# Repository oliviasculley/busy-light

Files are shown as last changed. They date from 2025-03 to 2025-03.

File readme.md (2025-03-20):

# Busy Light

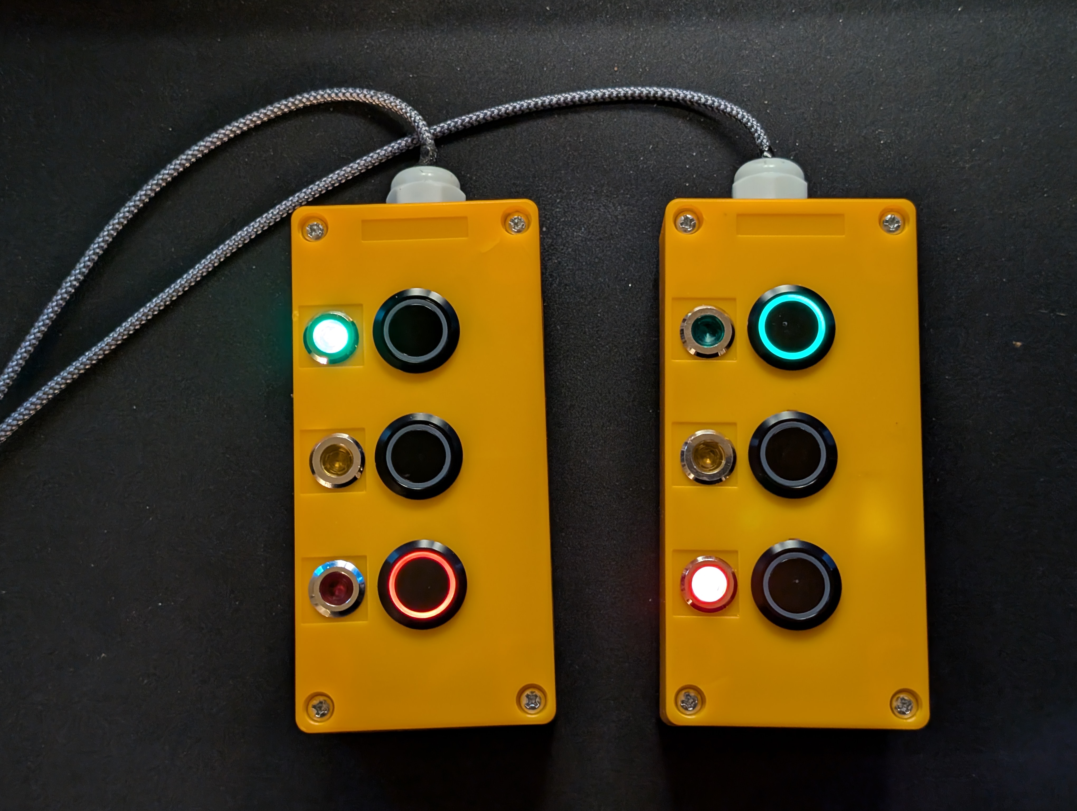
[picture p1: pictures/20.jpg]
Image of the busy light control boxes


This repo contains the schematics, PCB files and media for a synced busy-light
control box that can be used to communicate up to 4 states, indicated with LEDs. The wireless communication is fault-tolerant and utilizes encrypted ESP-NOW for communication, which means that it doesn't have any other dependencies besides power and your communications are secure!

## Schematic and PCB

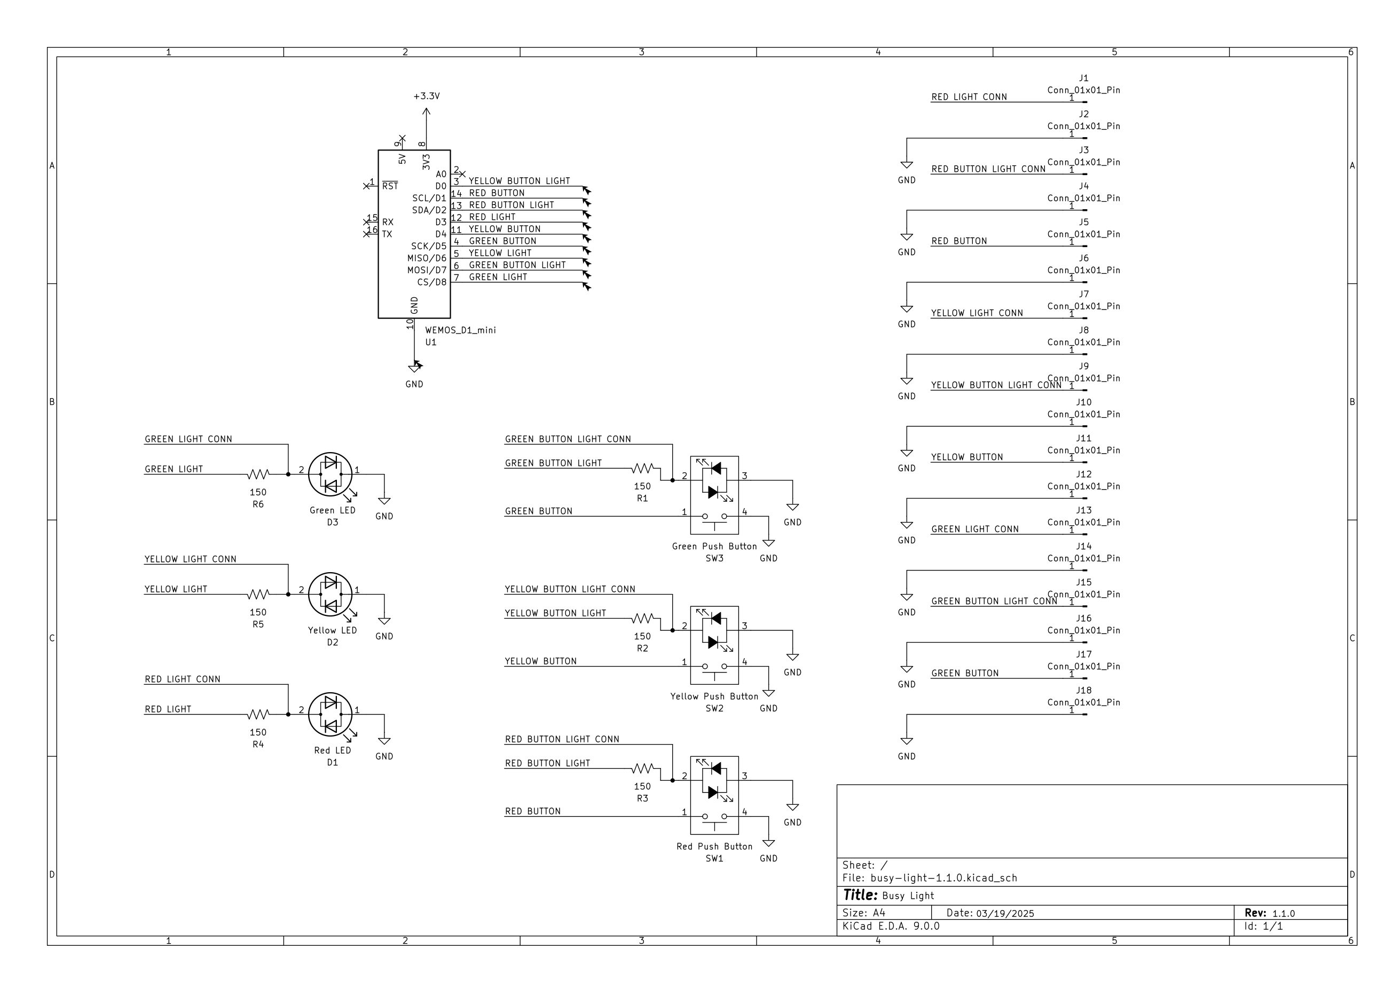
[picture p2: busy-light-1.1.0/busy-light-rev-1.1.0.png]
Busy light schematic

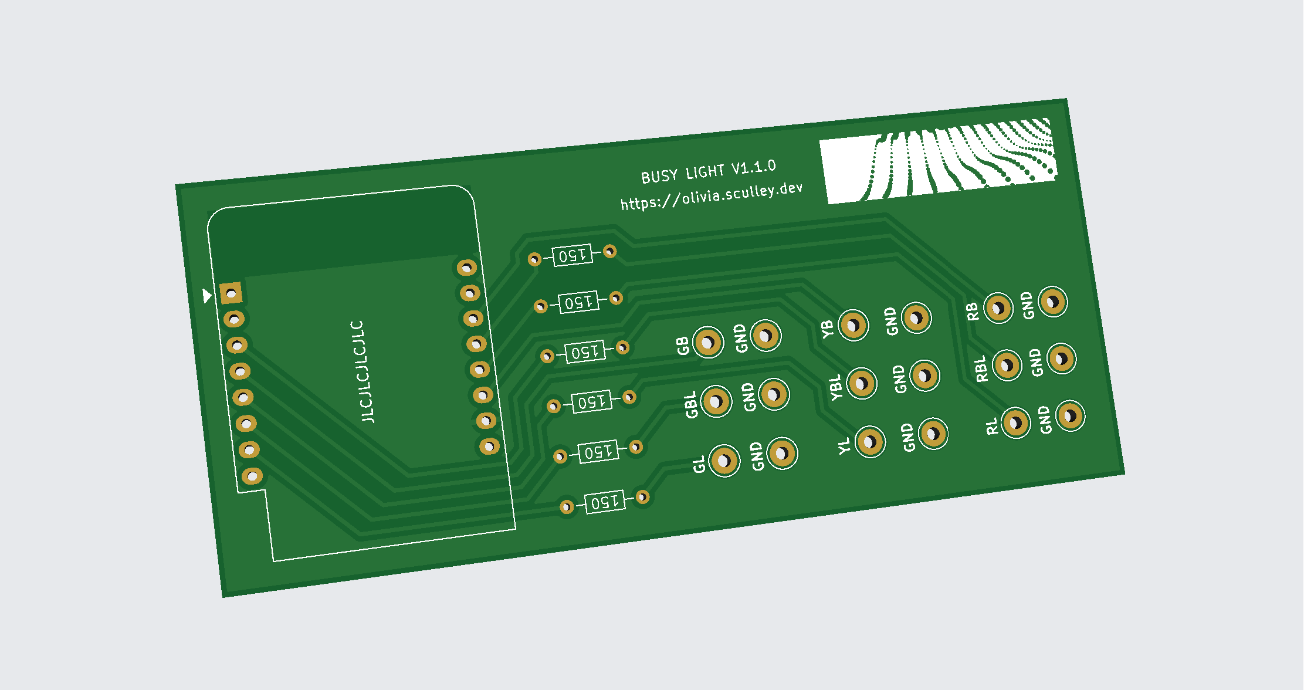
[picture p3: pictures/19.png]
A 3D view of the v1.1.0 revision of the PCB board


## Components

- [22mm 3x Control box](https://www.aliexpress.us/item/3256805247196863.html)
- [Red, Yellow and Green buttons](https://www.aliexpress.us/item/3256803827064988.html)
- [Button connector leads](https://www.aliexpress.us/item/3256803827064988.html)
- [LED Status Lights](https://www.aliexpress.us/item/2251832784127555.html)
- [Through-hole resistors](https://www.aliexpress.us/item/3256807885719870.html)
- [Wemos D1 Mini ESP 8266](https://www.amazon.com/dp/B081PX9YFV)
- [USB power brick](https://www.amazon.com/dp/B08H5421TJ)
- [Micro-USB cable](https://www.amazon.com/dp/B0D7RZJSPS)

Estimated part costs (without shipping):
- Two 22mm 3x Control boxes: $6.62
- Red, Yellow and Green buttons and connector leads: $20.76
- LED Status Lights: $5.34
- Wemos D1 Mini ESP 8266s: $12.98
- Through-hole resistors: $2.68
- USB power bricks: $11.99
- Micro-USB cables: $5.49

Estimated Total: around $66 for 2 boxes, or around $33 each

## Tools required

- Screwdriver
- Small eyeglasses screwdriver
- Soldering iron
- Solder
- Solid core wires
- Wire stripper
- Arduino IDE
- Kicad

## Assembly notes

- Use blue and white leads for button switches
- Use 150 ohm resistors for all LEDs
- For the Arduino IDE, you will need the [ESP8266 library](https://github.com/esp8266/Arduino) installed
- Epoxy putty around the cable is optional but recommended!
- To order the boards from JLCPCB yourself, visit the releases to download the compiled gerber files.
- The boards are set to 9600 baud serial
- Use serial to determine the board's mac addresses
- Then, fill in `BROADCAST_ADDRESS[]` with both boards' mac addresses
- Toggle the `#if true` between true and false to flash corresponding boxes
- (Optional) Set a new 16 char encryption key for better security

## Repository structure
- `busy-light-1.0.0/` contains the original version of the board that I created on a protoboard
- `busy-light-1.1.0/` contains the fabbed version of the board. I have yet to receive these boards and test them so no guarantees that it actually works! (although I have high hopes)

## Potential future changes
- Add mounting for PCB (Mounting holes?)
- Add mounting for Micro-USB cable
- Use FreeRTOS if I feel like writing a lot of boilerplate

## Project Log

1. The first prototype boards
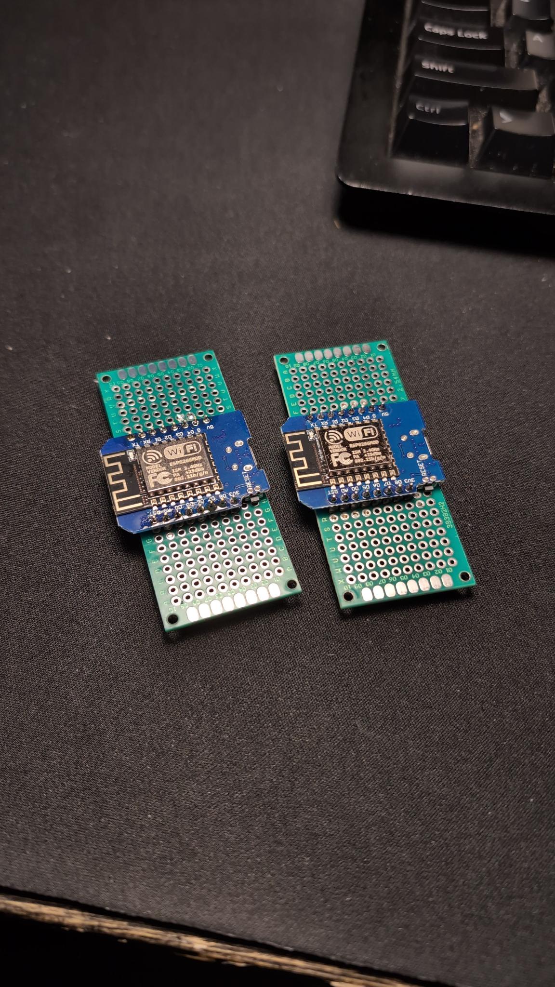
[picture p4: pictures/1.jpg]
The first prototype boards
   
1. Soldering the resistors
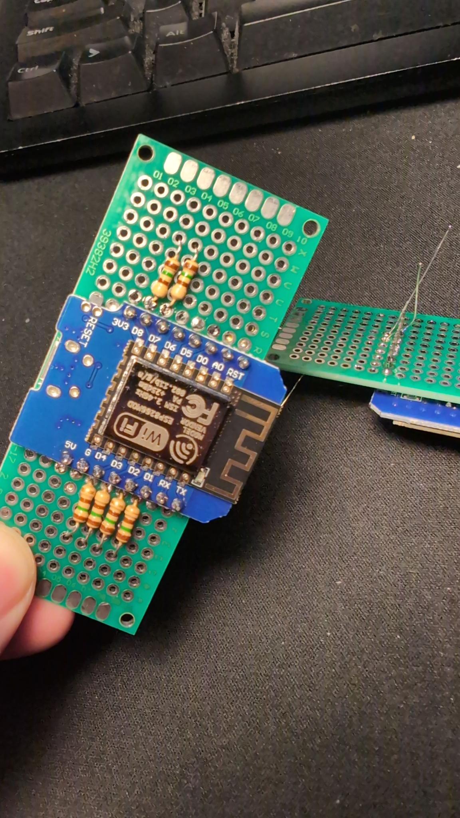
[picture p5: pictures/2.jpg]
Soldering the resistors
   
1. Wrapping wires around pins
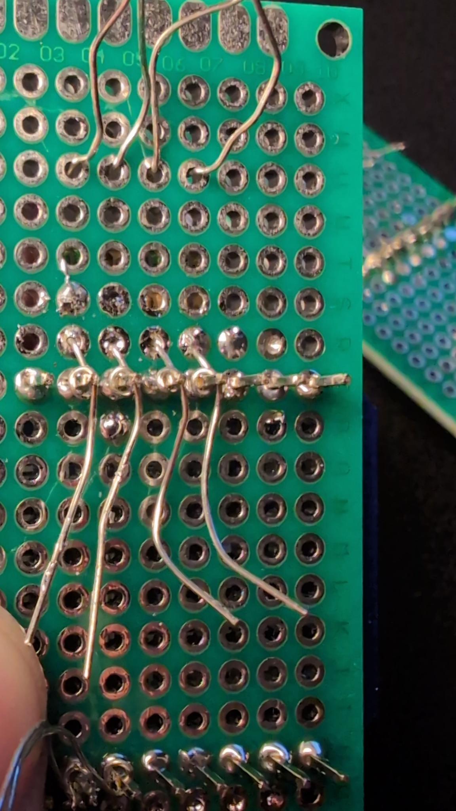
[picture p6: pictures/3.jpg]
Wrapping wires around pins
   
1. Trimmed wires
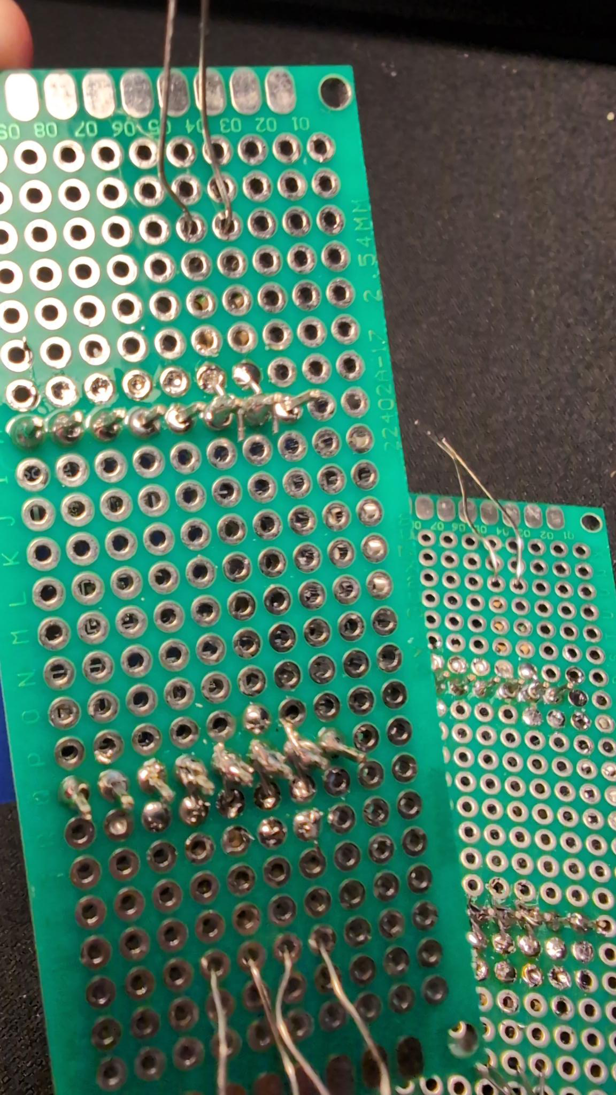
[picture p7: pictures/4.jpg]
Trimmed wires
   
1. Wired up prototype boards. Do you see the mistake?
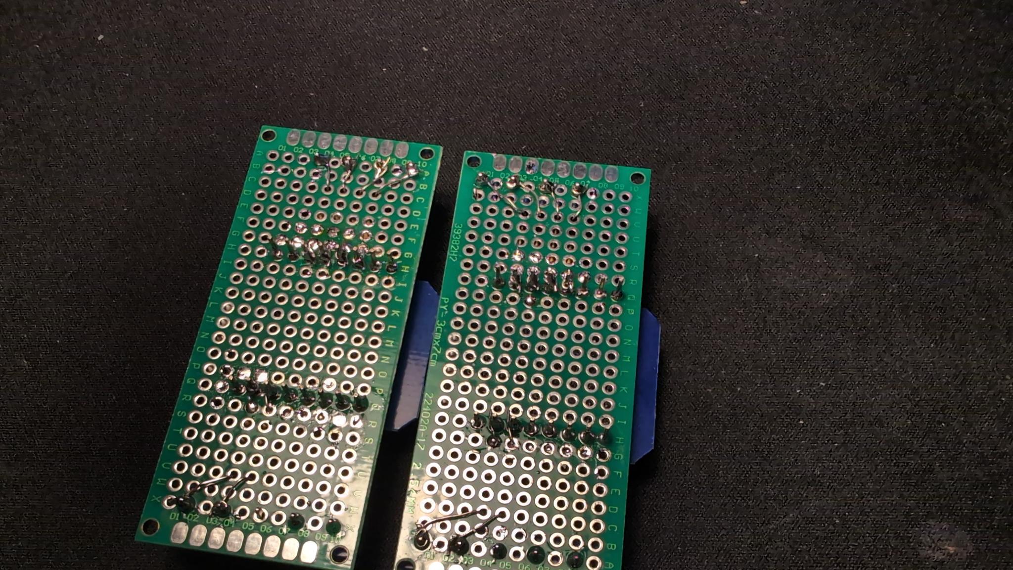
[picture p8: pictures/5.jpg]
Wired up prototype boards. Do you see the mistake?
   
1. Adding screw terminals
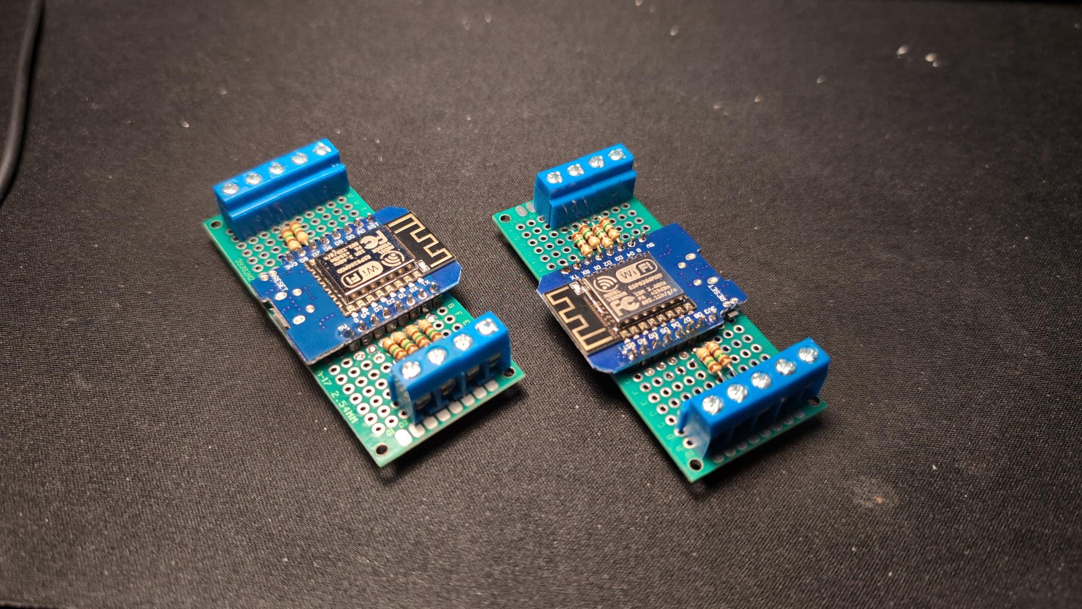
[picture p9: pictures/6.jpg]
Adding screw terminals
   
1. Fixing my mistake (Please excuse the soldering, most of this project was done after midnight 😅😅😅)
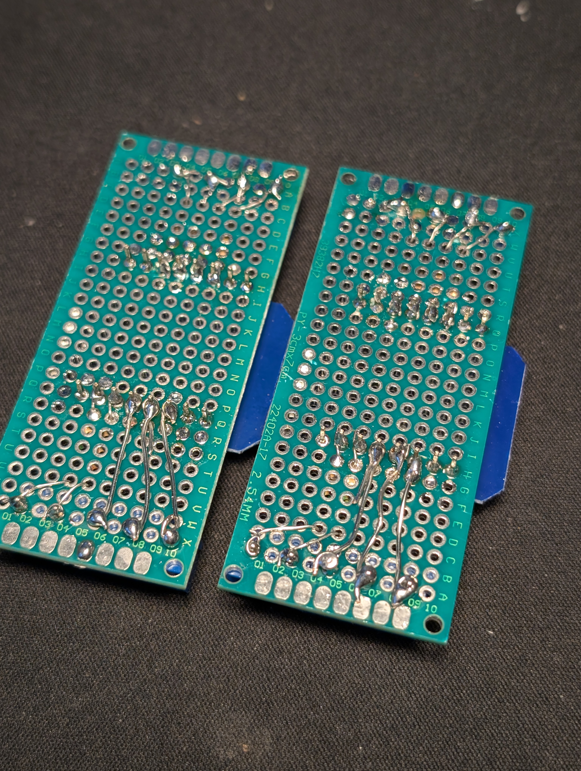
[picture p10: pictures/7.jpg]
Fixing my mistake
   
1. Wiring up buttons and lights
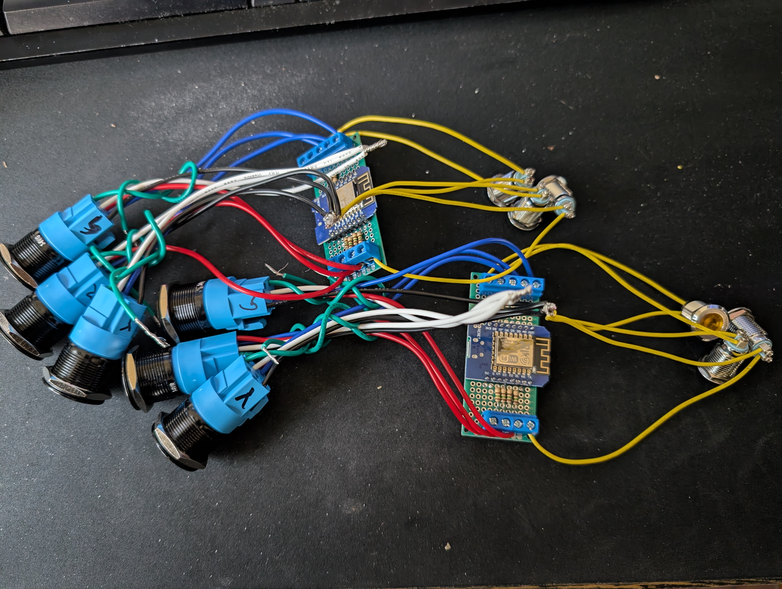
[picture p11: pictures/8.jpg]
Wiring up buttons and lights
   
1. Installing switches into control boxes
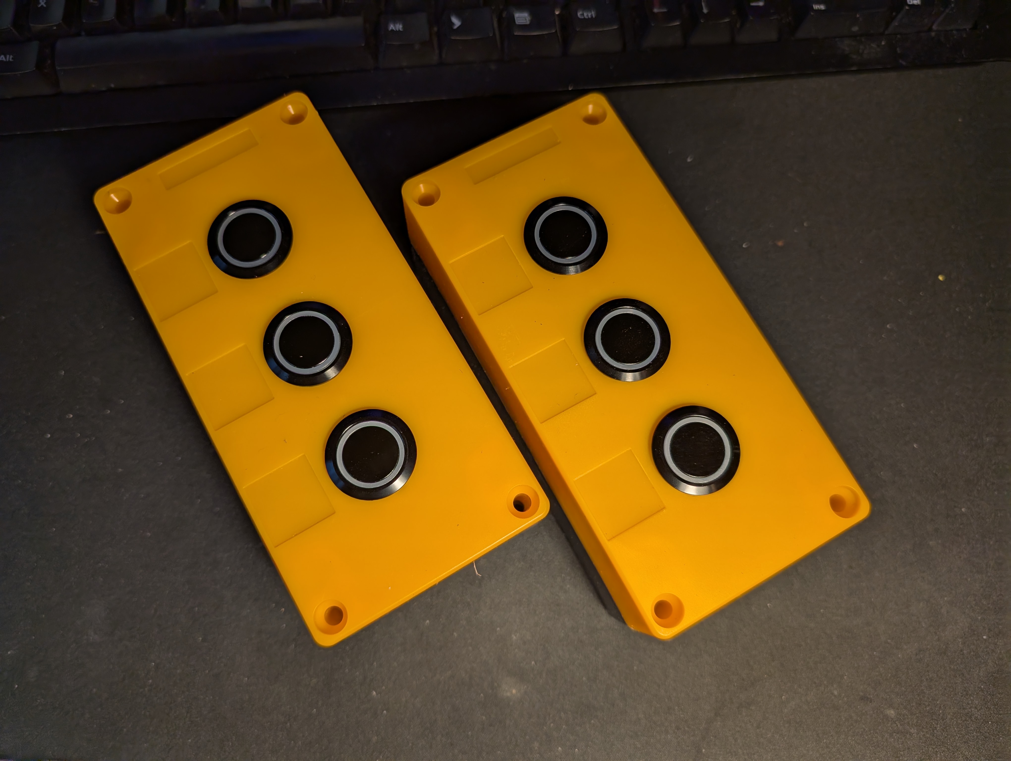
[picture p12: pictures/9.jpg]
Installing switches into control boxes
   
1. Adding a pull-up resistor to pin D0. Turns out that the ESP8266 doesn't have a usable internal pull-up on D0. Something to keep in mind!
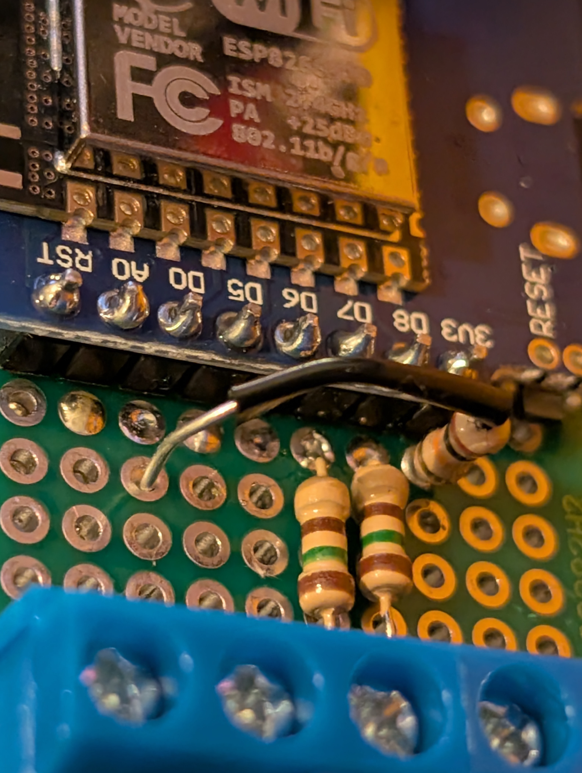
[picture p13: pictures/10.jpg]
Adding a pull-up resistor
   
1. The boxes mid-assembly!
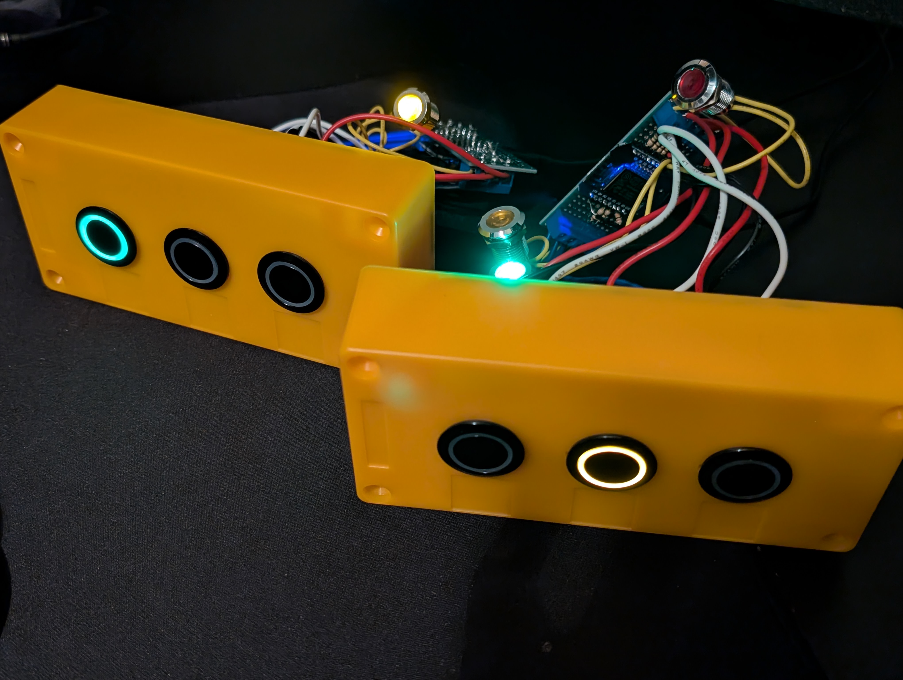
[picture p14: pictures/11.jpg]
The boxes mid-assembly!
   
1. Filling the end-caps with epoxy putty
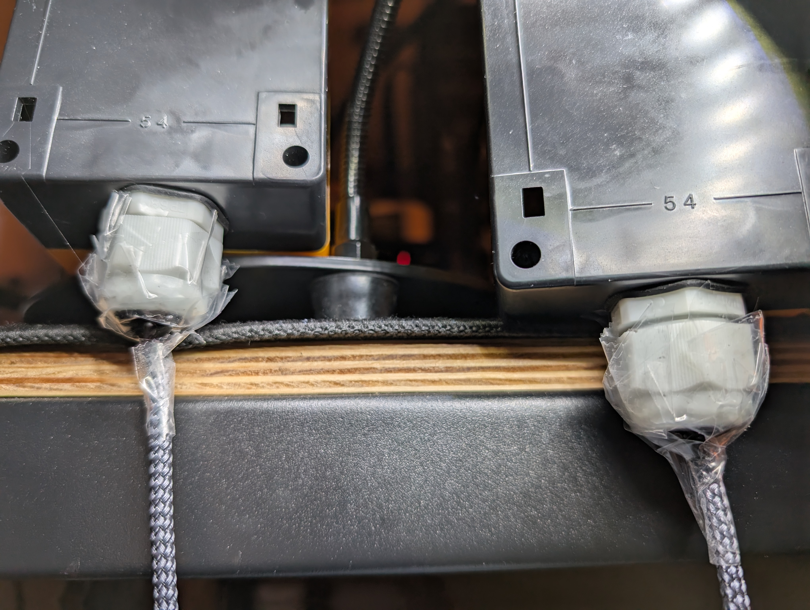
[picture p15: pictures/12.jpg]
Filling the end-caps with epoxy putty
   
1. An early version of the PCB board
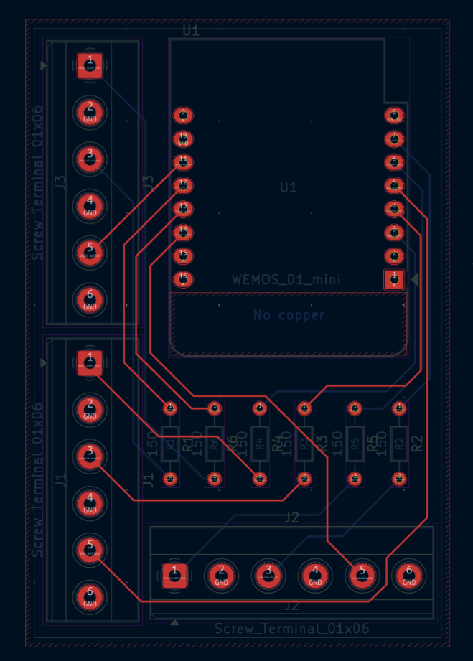
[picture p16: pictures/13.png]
An early version of the PCB board front
   
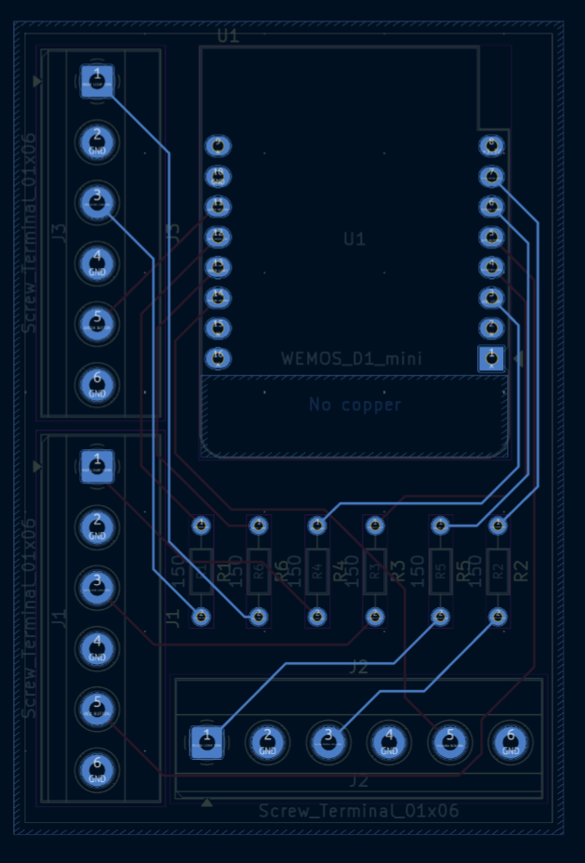
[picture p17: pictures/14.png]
An early version of the PCB board back
   
1. A 3D view of an early version of the PCB board
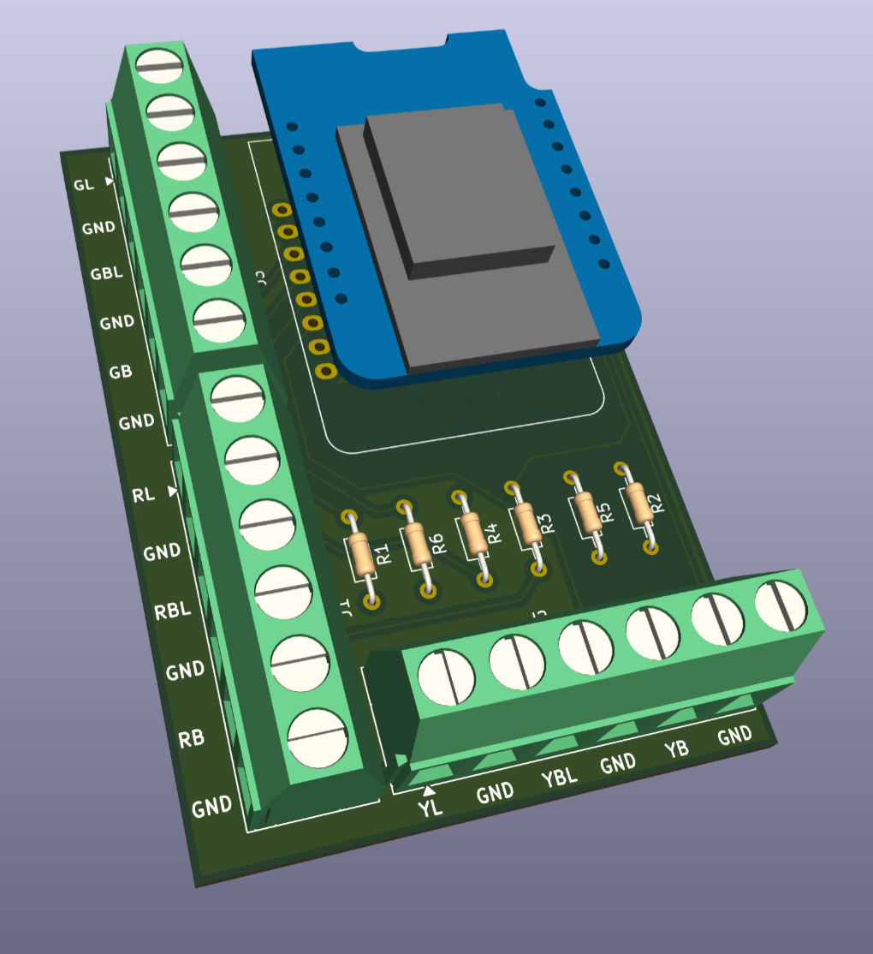
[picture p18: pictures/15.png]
A 3D view of an early version of the PCB boardboards
   
1. A 3D view of an early version of just the PCB board
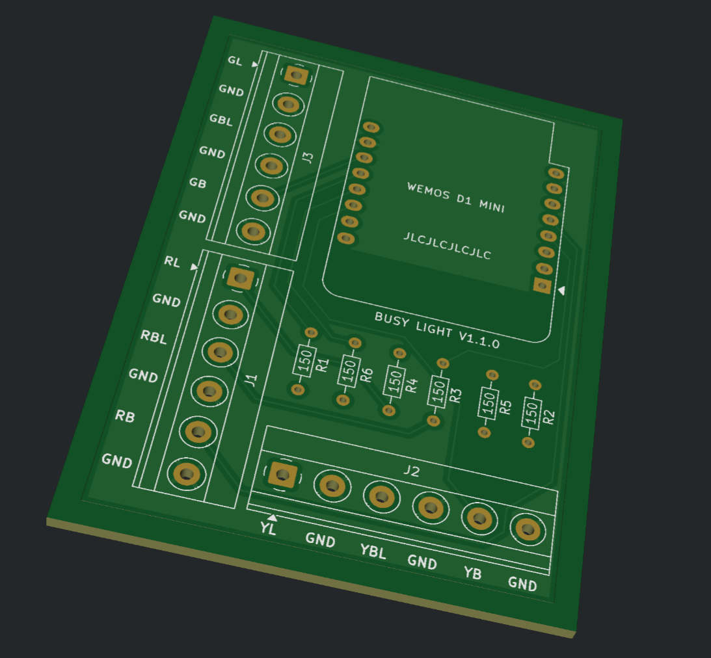
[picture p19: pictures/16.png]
A 3D view of an early version of just the PCB board
   
1. A 3D view of another revision of the PCB board
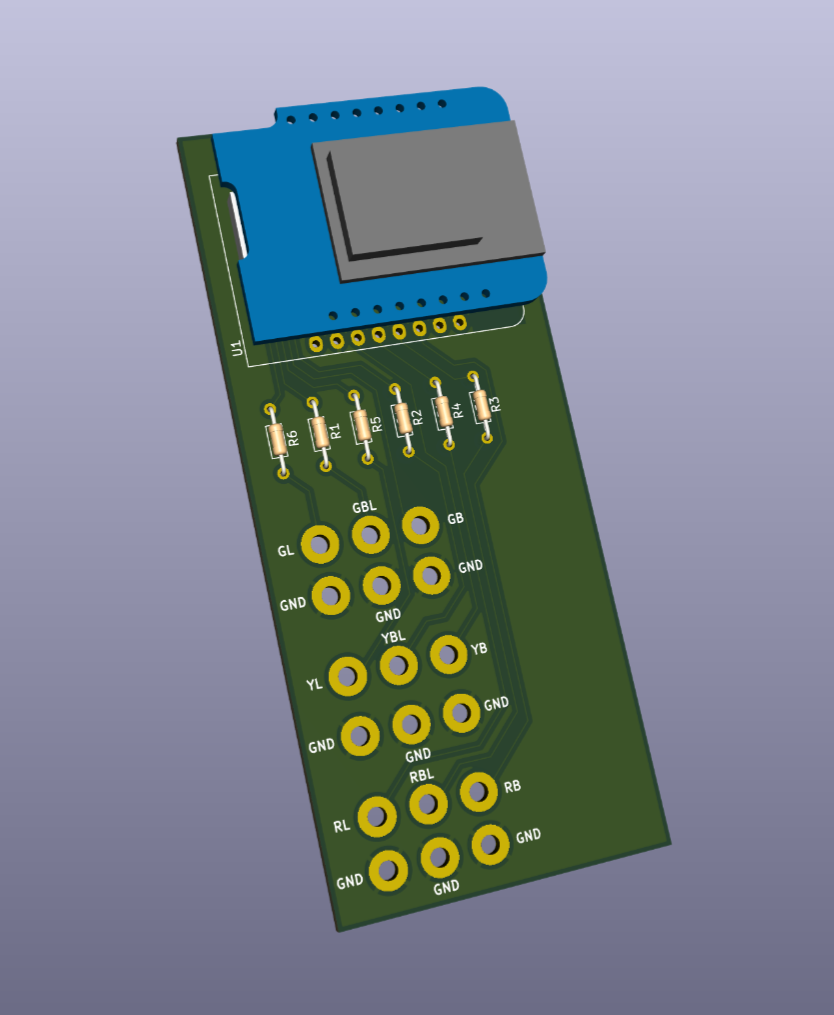
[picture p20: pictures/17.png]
A 3D view of another revision of the PCB board
   
1. A 3D view of the v1.1.0 revision of just the PCB board
   A 3D view of the v1.1.0 revision of just the PCB board
1. The final working prototypes! (Not using the fabbed boards yet, stay tuned!)
   The final working prototypes! (Not using the fabbed boards yet, stay tuned!)

## Misc Notes

- Vf red led button: 1.87v @ 3.4v
- Vf yellow led button: 2.58v @ 3.5v
- Vf green led button: 2.54v @ 3.6v

---

- Vf red: 1.84v @ 3.7v
- Vf yellow: 1.92v @ 3.8v
- Vf green: 2.30v @ 4.0v

---

- (3 - 1.85) / 20 (milliamps) * 1000 = 57 ohm
- (3 - 2.6) / 20 (milliamps) * 1000 = 20 ohm
- (4 - 1.85) / 20 (milliamps) * 1000 = 108 ohm
- (4 - 2.6) / 20 (milliamps) * 1000 = 70 ohm
- 150 ohm resistors seem good enough

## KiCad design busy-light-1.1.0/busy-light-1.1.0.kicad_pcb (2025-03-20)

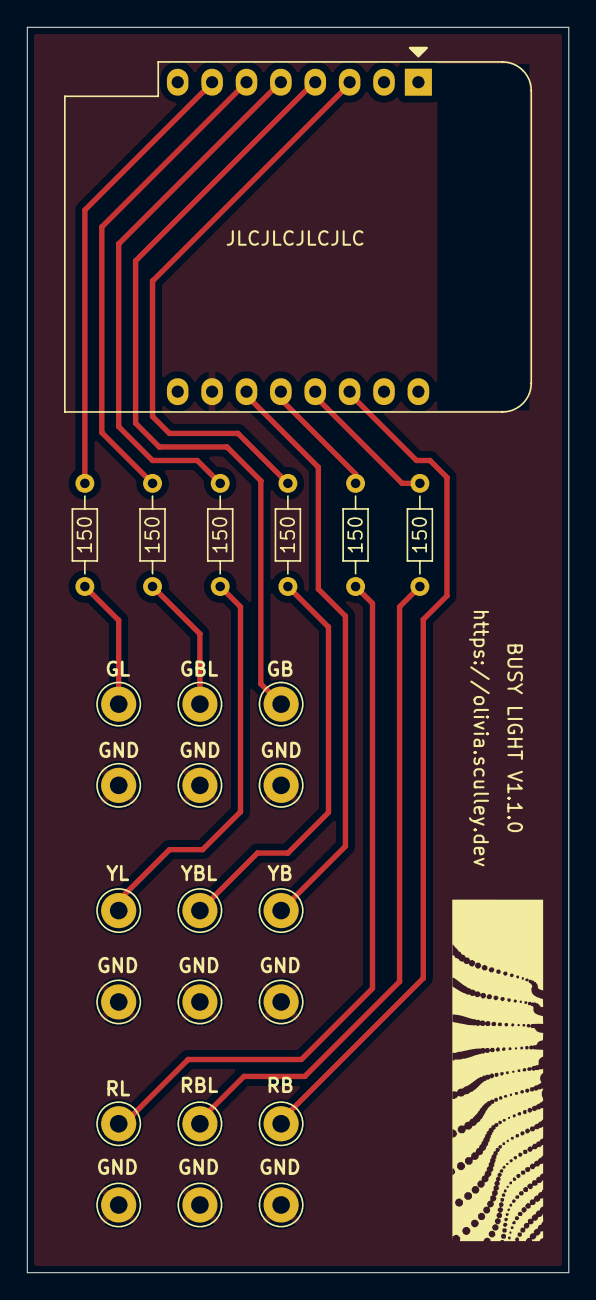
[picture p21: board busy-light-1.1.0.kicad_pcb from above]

Board: 4 copper layers, 40.0 x 92.0 mm, 25 parts (0 on the bottom side), 16 nets.

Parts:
J1, J2, J3, J4, J5, J6, J7, J8, J9, J10, J11, J12, J13, J14, J15, J16, J17, J18: Conn_01x01_Pin; Pin_D1.3mm_L11.0mm
R1, R2, R3, R4, R5, R6: 150; R_Axial_DIN0204_L3.6mm_D1.6mm_P7.62mm_Horizontal
U1: WEMOS_D1_mini; WEMOS_D1_mini_light

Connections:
/GREEN BUTTON: J17.1, U1.4 (SCK/D5)
/GREEN BUTTON LIGHT: R1.1, U1.6 (MOSI/D7)
/GREEN BUTTON LIGHT CONN: J15.1, R1.2
/GREEN LIGHT: R6.1, U1.7 (CS/D8)
/GREEN LIGHT CONN: J13.1, R6.2
/RED BUTTON: J5.1, U1.14 (SCL/D1)
/RED BUTTON LIGHT: R3.1, U1.13 (SDA/D2)
/RED BUTTON LIGHT CONN: J3.1, R3.2
/RED LIGHT: R4.1, U1.12 (D3)
/RED LIGHT CONN: J1.1, R4.2
/YELLOW BUTTON: J11.1, U1.11 (D4)
/YELLOW BUTTON LIGHT: R2.1, U1.3 (D0)
/YELLOW BUTTON LIGHT CONN: J9.1, R2.2
/YELLOW LIGHT: R5.1, U1.5 (MISO/D6)
/YELLOW LIGHT CONN: J7.1, R5.2
GND: J2.1, J4.1, J6.1, J8.1, J10.1, J12.1, J14.1, J16.1, J18.1, U1.10 (GND)

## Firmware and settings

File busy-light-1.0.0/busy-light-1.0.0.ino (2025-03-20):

#include <espnow.h>
#include <ESP8266WiFi.h>

#define RED_BUTTON_LIGHT D4
#define YELLOW_BUTTON_LIGHT D3
#define GREEN_BUTTON_LIGHT D2
#define RED_LIGHT D1
#define YELLOW_LIGHT D8
#define GREEN_LIGHT D7
#define RED_BUTTON D6
#define YELLOW_BUTTON D5
#define GREEN_BUTTON D0

const uint8_t BUTTON_LIGHTS[] = {
  RED_BUTTON_LIGHT,
  YELLOW_BUTTON_LIGHT,
  GREEN_BUTTON_LIGHT
};
const uint8_t STATUS_LIGHTS[] = { RED_LIGHT, YELLOW_LIGHT, GREEN_LIGHT };
const uint8_t BUTTONS[] = { RED_BUTTON, YELLOW_BUTTON, GREEN_BUTTON };

enum Status { NONE, NO_CALL, CAUTION, AUDIO_CALL, VIDEO_CALL };
Status selfStatus = NONE;
Status otherStatus = NONE;

// Toggle me to flash corresponding boxes
#if true
uint8_t BROADCAST_ADDRESS[] = {0x00, 0x00, 0x00, 0x00, 0x00, 0x00};
#else
uint8_t BROADCAST_ADDRESS[] = {0x00, 0x00, 0x00, 0x00, 0x00, 0x00};
#endif

unsigned char* ESPNOW_KEY = (unsigned char*) "your-16-char-encryption-key-here";
struct Broadcast { uint8_t status; bool confirm; };
Broadcast sendingStatus;
Broadcast sendingConfirmation;
bool receive = true;
int rebroadcastCounter = 0;
#define REBROADCAST_INTERVAL 100
#define HOLD_THRESHOLD 10
int heldCounter = 0;

void setup() {
  Serial.begin(9600);
  Serial.println("==============");
  Serial.println("===NEW BOOT===");
  Serial.println("==============");

  for(uint8_t buttonLight : BUTTON_LIGHTS) {
    pinMode(buttonLight, OUTPUT);
    digitalWrite(buttonLight, LOW);
  }
  for(uint8_t statusLight : STATUS_LIGHTS) {
    pinMode(statusLight, OUTPUT);
    digitalWrite(statusLight, LOW);
  }
  for(uint8_t button : BUTTONS) {
    pinMode(button, INPUT_PULLUP);
  }

  sendingStatus.status = NONE;
  sendingStatus.confirm = false;

  sendingConfirmation.status = NONE;
  sendingConfirmation.confirm = true;

  WiFi.mode(WIFI_STA);
  Serial.print("ESP Board MAC Address:  ");
  Serial.println(WiFi.macAddress());

  if (esp_now_init() != 0) {
    Serial.println("Error initializing ESP-NOW");
    return;
  }
  esp_now_set_self_role(ESP_NOW_ROLE_COMBO);
  esp_now_add_peer(
    BROADCAST_ADDRESS,
    ESP_NOW_ROLE_COMBO,
    1,
    ESPNOW_KEY,
    sizeof(ESPNOW_KEY)
  );
  esp_now_register_recv_cb(esp_now_recv_cb_t(readStatus));
}

void loop() {
  if (!digitalRead(GREEN_BUTTON))
    sendingStatus.status = NO_CALL;

  if (!digitalRead(YELLOW_BUTTON))
    sendingStatus.status = CAUTION;

  if (heldCounter > HOLD_THRESHOLD && !digitalRead(RED_BUTTON))
    sendingStatus.status = VIDEO_CALL;
  else if (!digitalRead(RED_BUTTON)) {
    heldCounter++;
    sendingStatus.status = AUDIO_CALL;
  } else
    heldCounter = 0;

  sendSelfStatus();
  delay(50);
}

void sendSelfStatus() {
  rebroadcastCounter++;
  if (rebroadcastCounter < REBROADCAST_INTERVAL && sendingStatus.status == selfStatus) return;
  rebroadcastCounter = 0;

  Serial.print("Sending self status ");
  Serial.println(getStatusStr((Status) sendingStatus.status));

  esp_now_send(
    BROADCAST_ADDRESS,
    (uint8_t *) &sendingStatus,
    sizeof(sendingStatus)
  );
}

void readStatus(uint8_t * mac, uint8_t * incomingData, uint8_t len) {
  if (((Broadcast*) incomingData)->confirm) {
    selfStatus = (Status) ((Broadcast*) incomingData)->status;
    Serial.print("Set self status ");
    Serial.println(getStatusStr(selfStatus));
    setButtonLights(selfStatus);
  } else {
    sendingConfirmation.status = ((Broadcast*) incomingData)->status;
    Serial.print("Sending other status ");
    Serial.println(getStatusStr((Status) sendingConfirmation.status));

    uint8_t result = esp_now_send(
      BROADCAST_ADDRESS,
      (uint8_t *) &sendingConfirmation,
      sizeof(sendingConfirmation)
    );
    if (result != 0) return;

    otherStatus = (Status) ((Broadcast*) incomingData)->status;
    
    Serial.print("Set other status ");
    Serial.println(getStatusStr(otherStatus));
    setStatusLights(otherStatus);
  }
}

// helpers

const char* getStatusStr(Status status) {
  switch (status) {
    case NO_CALL:
      return "No Call";
    case CAUTION:
      return "Caution";
    case AUDIO_CALL:
      return "Audio Call";
    case VIDEO_CALL:
      return "Video Call";
    default:
      return "None";
  }
}

void setButtonLights(Status status) {
  for (uint8_t light : BUTTON_LIGHTS)
    digitalWrite(light, LOW);

  switch (status) {
    case NO_CALL:
      digitalWrite(GREEN_BUTTON_LIGHT, HIGH);
      break;
    case CAUTION:
      digitalWrite(YELLOW_BUTTON_LIGHT, HIGH);
      break;
    case AUDIO_CALL:
      digitalWrite(RED_BUTTON_LIGHT, HIGH);
      break;
    case VIDEO_CALL:
      digitalWrite(YELLOW_BUTTON_LIGHT, HIGH);
      digitalWrite(RED_BUTTON_LIGHT, HIGH);
      break;
    default:
      break;
  }
}

void setStatusLights(Status status) {
  for (uint8_t light : STATUS_LIGHTS)
    digitalWrite(light, LOW);

  switch (status) {
    case NO_CALL:
      digitalWrite(GREEN_LIGHT, HIGH);
      break;
    case CAUTION:
      digitalWrite(YELLOW_LIGHT, HIGH);
      break;
    case AUDIO_CALL:
      digitalWrite(RED_LIGHT, HIGH);
      break;
    case VIDEO_CALL:
      digitalWrite(YELLOW_LIGHT, HIGH);
      digitalWrite(RED_LIGHT, HIGH);
      break;
    default:
      break;
  }
}

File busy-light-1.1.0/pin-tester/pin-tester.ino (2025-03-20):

#define GREEN_BUTTON D5
#define GREEN_BUTTON_LIGHT D7
#define GREEN_LIGHT D8

#define YELLOW_BUTTON D4
#define YELLOW_BUTTON_LIGHT D0
#define YELLOW_LIGHT D6

#define RED_BUTTON D1
#define RED_BUTTON_LIGHT D2
#define RED_LIGHT D3

int counter = 0;
int lightCount = 0;

void setup() {
  Serial.begin(9600);
  Serial.println("==============");
  Serial.println("===NEW BOOT===");
  Serial.println("==============");

  pinMode(GREEN_BUTTON_LIGHT, OUTPUT);
  digitalWrite(GREEN_BUTTON_LIGHT, LOW);

  pinMode(GREEN_LIGHT, OUTPUT);
  digitalWrite(GREEN_LIGHT, LOW);

  pinMode(YELLOW_BUTTON_LIGHT, OUTPUT);
  digitalWrite(YELLOW_BUTTON_LIGHT, LOW);

  pinMode(YELLOW_LIGHT, OUTPUT);
  digitalWrite(YELLOW_LIGHT, LOW);

  pinMode(RED_BUTTON_LIGHT, OUTPUT);
  digitalWrite(RED_BUTTON_LIGHT, LOW);

  pinMode(RED_LIGHT, OUTPUT);
  digitalWrite(RED_LIGHT, LOW);

  pinMode(GREEN_BUTTON, INPUT_PULLUP);
  pinMode(YELLOW_BUTTON, INPUT_PULLUP);
  pinMode(RED_BUTTON, INPUT_PULLUP);
}

void loop() {
  if (!digitalRead(GREEN_BUTTON))
    Serial.println("GREEN_BUTTON");
  if (!digitalRead(YELLOW_BUTTON))
    Serial.println("YELLOW_BUTTON");
  if (!digitalRead(RED_BUTTON))
    Serial.println("RED_BUTTON");
  
  if (counter > 6) {
    lightCount++;
    if (lightCount > 6)
      lightCount = 0;
    digitalWrite(GREEN_LIGHT, lightCount == 1);
    digitalWrite(YELLOW_LIGHT, lightCount == 2);
    digitalWrite(RED_LIGHT, lightCount == 3);
    digitalWrite(GREEN_BUTTON_LIGHT, lightCount == 4);
    digitalWrite(YELLOW_BUTTON_LIGHT, lightCount == 5);
    digitalWrite(RED_BUTTON_LIGHT, lightCount == 6);
    counter = 0;
  } else {
    counter += 1;
  }

  delay(50);
}

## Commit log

2025-03-20 remove board design screenshot
2025-03-20 add PCB image at top
